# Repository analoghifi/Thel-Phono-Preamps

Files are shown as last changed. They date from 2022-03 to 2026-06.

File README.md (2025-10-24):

### "High-End":  
* predecessor models:
  * "VX-5021P" 1996 ➔ https://web.archive.org/web/20160323223326/http://thel-audioworld.de/test/test.htm#VX5021
  * "Phono-M" 2006 ➔ https://web.archive.org/web/20070626215210/http://www.thel-audioworld.de/module/phono/phono-M.htm
  * "Phono-HQ" 12/2017 ➔ https://web.archive.org/web/20180203013342/http://www.thel-audioworld.de/module/phono/phono-hq.htm
* <b>\"<a href="/hardware/beautiful%20noise">Beautiful-Noise</a>\" 09/2018</b>  
Stereo module / 2 channels galvanically isolated / single ended inputs, single ended outputs  
two-stage passive RIAA-filter  
adjustable gain (6-step) / input resistance changeable (by soldering) / input capacity changeable (by soldering)  
➔ https://web.archive.org/web/20190110103246/http://www.thel-audioworld.de/module/phono/Phonovorstufe-B.htm

### "Ultra-High-End":  
* predecessor models:
  * "Majestic" 1998 ➔ https://web.archive.org/web/20160323223326/http://thel-audioworld.de/test/test.htm#Majestic
  * "VP2000" 2002 ➔ https://web.archive.org/web/20020410123225/http://thel-audioworld.de/module/phono/phono.htm
  * "Phono-X" 2007-2017 ➔ https://web.archive.org/web/20070312044356/http://www.thel-audioworld.de/module/phono/phono.htm
  * "Phono HQX" 12/2017 ➔ https://web.archive.org/web/20180203012402/http://www.thel-audioworld.de/module/phono/phono-hqx.htm
* <b>\"<a href="/hardware/sound%20of%20silence">Sound of Silence</a>\" 09/2018</b>  
Mono module / true\* fully symmetrical / balanced input -> balanced filter stages -> balanced output  
\*(no ground reference at any point in the audio signal chain)  
two-stage passive balanced RIAA-filter  
adjustable input resistor (16-step) / adjustable input capacity (16-step) / adjustable gain (16-step)  
➔ https://web.archive.org/web/20190109011016/http://www.thel-audioworld.de/module/phono/Phonovorstufe-S.htm  

----  
calculation of the R C Values for the passive 2-step (inverse) RIAA filter:  
https://docs.google.com/spreadsheets/d/1qcIyMvDhxXAbTDFzf901tkU7BbxNvI2y0nLj_5HbEa4/edit?usp=sharing  

----  
#### "Beautiful-Noise":  
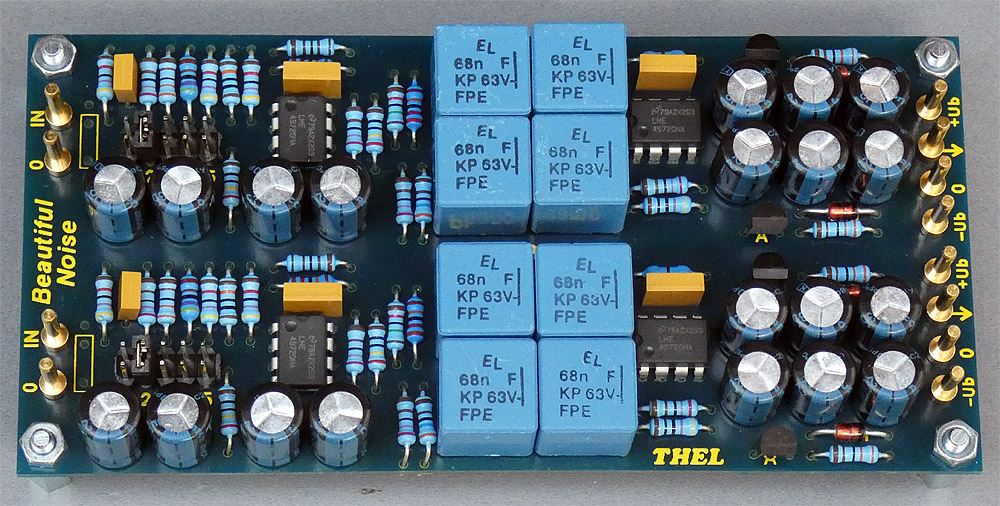
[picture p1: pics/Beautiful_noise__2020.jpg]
  
  
.  
  
#### "Sound of Silence":  
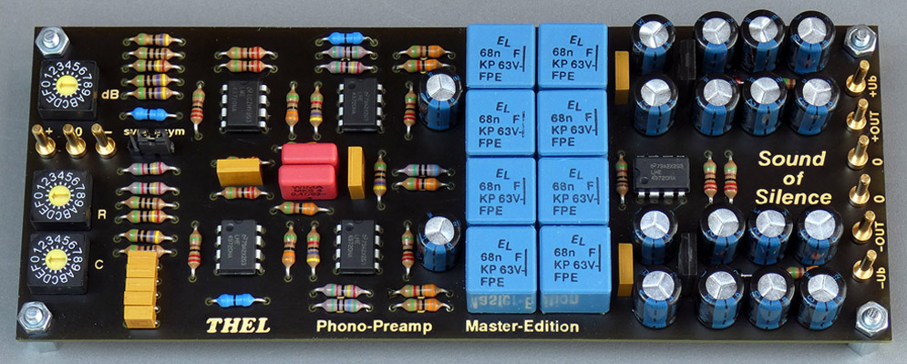
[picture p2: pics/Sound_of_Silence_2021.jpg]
  
  
----  
### Kicad projects in this repo:  
* ["Sound of Silence"](https://github.com/analoghifi/Thel-Phono-Preamps/tree/main/hardware/sound%20of%20silence/KiCad/original) | state: initial release v1.01 | like the original, 1-layer, THT
* ["Sound of Silence WIMA Edition"](https://github.com/analoghifi/Thel-Phono-Preamps/tree/main/hardware/sound%20of%20silence/KiCad/WIMA-Edition) | state: initial release v1.01 | all WIMA Caps | like the original, 1-layer, THT
* ["Beautiful Noise"](https://github.com/analoghifi/Thel-Phono-Preamps/tree/main/hardware/beautiful%20noise/KiCad/original) | state: coming soon... | like the original, 1-layer, THT

----

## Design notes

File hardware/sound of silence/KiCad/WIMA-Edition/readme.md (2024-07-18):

### This special edition exclusively uses the highly valued WIMA polypropylene capacitors throughout  
(FKP = highest quality film/foil types for the passive RIAA filter and the input (load-) Capacitors)  
* C101,C102,C201..C214 = WIMA FKP2 33nF 63V 1% (tanδ = 0.0005)  
* C3,C4,C6 = WIMA FKP2 100V 1% (tanδ = 0.0005)
* C5,C7 = WIMA FKP2 47pF 1000V 2.5% (tanδ = 0.0005)
* C8,C9,C12,C13,C14,C15 = WIMA MKP2 63V 5% (tanδ = 0.0005)  
  
see -> [List of used capacitors for the "WIMA-Edition"](https://github.com/analoghifi/Thel-Phono-Preamps/blob/main/hardware/sound%20of%20silence/KiCad/WIMA-Edition/Capacitor_BOM.md)  
  
#### this is not the original Thel PCB but it's very like\* the original with the following exceptions:  
* different board dimensions original: 155mm x 60mm -> this PCB: 155mm x 64mm  
* different mounting hole spacing original: 148mm x 53mm -> this PCB: 148mm x 57mm  
* "C2" is 462nF (paralleled 14x33nF Wima FKP2 1%) 
* "C1" is 66nF (paralleled 2x33nF Wima FKP2 1%)
* "C1" is in a different location on the board  
* using WIMA FKP2 (instead of ceramics) for the input (load-) Capacitors as well C3 ..C7  
* more massive ground and power supply PCB tracks  
* additional GND track unterneath U1 and U2 
  
\*(same schematic / same 1-layer\** layout THT / same THT components in the same places on the board)  
\**(strictly speaking, this KiCad PCB is a two-layer PCB with plated-through holes, but you can also (let) produce it as a classic 1-layer PCB with non-plated holes if you wish, since all the tracks are on the bottom side only)  

----  

### remarks:  
#### R6,R7:  
one can use 23,7kΩ or 24kΩ instead  
or use 2x47kΩ in parallel each  
when using MM-Systems (choosing R<sub>in</sub> = 47kΩ [SW2=0]):  
for lower noise one may use low-TCR-types (25ppm/°C or lower) if available  
e.g. Vishay "[CMF Industrial](https://www.mouser.com/c/passive-components/resistors/film-resistors/metal-film-resistors-through-hole/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)" series  
or Vishay [PTF series](https://www.mouser.de/c/passive-components/resistors/film-resistors/metal-film-resistors-through-hole/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) (even lower TCR)  
or Tyco (TE Connectivity) type "[YR1B23k7CC](https://www.mouser.com/ProductDetail/TE-Connectivity-Holsworthy/YR1B23K7CC?qs=n4i9pByFsMSkJXItUSDcPw%3D%3D)" (23.7kΩ / 0.1% / 15ppm/°C) [from the Tyco ["YR1-series" (R-series)](https://www.mouser.com/c/passive-components/resistors/film-resistors/metal-film-resistors-through-hole/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)]  
#### U1,U2,U3,U4,U5:  
instead of [LME49720](https://www2.mouser.com/ProductDetail/Texas-Instruments/LME49720NA-NOPB?qs=7lkVKPoqpbYtIqwyg5iDaA%3D%3D) you can use [LM4562](https://www2.mouser.com/ProductDetail/Texas-Instruments/LM4562NA-NOPB?qs=QbsRYf82W3Gc2w4DLq%252BZjw%3D%3D) (both Texas Instruments),  
these two are 100% identical (even regarding their inner guts).
  
----  
  
these are KiCad 6.x projects  
see how to get the proper 3D-Models from here: https://github.com/analoghifi/KiCad-3D-Models
  
----  
  
use kicanvas.org to view this KiCad project in your browser:  
https://kicanvas.org/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

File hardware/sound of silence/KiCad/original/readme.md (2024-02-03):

this is not the original Thel PCB but it's very like\* the original with the following exceptions:  
* different board dimensions original: 155mm x 60mm -> this PCB: 155mm x 69.65mm  
* different mounting hole spacing original: 148mm x 53mm -> this PCB: 148mm x 62mm  
* make use of my \"universal capacitor footprint\" for the filter caps (C1,C21,C22,C23,C24,C25,C26,C27) -> see here T.B.D.  
* C1 is in a different location on the board  
* using a combined 5.0mm/7.5mm pin spacing footprint for all other small (foil and ceramic) caps (C3,C4,C5,C6,C7,C8,C9,C10,C11,C14,C15)  
* more massive ground and power supply PCB tracks  
* additional GND track unterneath U1 and U2 
  
\*(same schematic / same 1-layer\** layout THT / same THT components in the same places on the board)  
\**(strictly speaking, this KiCad PCB is a two-layer PCB with plated-through holes, but you can also (let) produce it as a classic 1-layer PCB with non-plated holes if you wish, since all the tracks are on the bottom side only)  

----  

### remarks:  
#### C3,C4,C5,C6,C7:  
use ceramic C0G capacitors (tolerance: 1% to 2,5% / rated DC Voltage: 50V, 63V or 100V / pitch 5mm or 7,5mm)  
e.g. KEMET "[goldmax 300](https://github.com/analoghifi/capacitors/blob/main/audio%20and%20filter%20capacitors/docs/datasheets/C0G/KEMET_C1049_GOLDMAX_C0G_THT.pdf)" Series in THT version  
The dielectric material is important here: Do NOT use ceramic capacitors with a dielectric other than C0G (NP0) !  
or alternatively if you don't like ceramic capacitors:  
small polypropylene Film/Foil Capacitors (tolerance: 1% to 2,5% / rated DC Voltage: 63V or 100V / pitch 5mm or 7,5mm)  
e.g. KEMET [PFR-("Evox")](https://github.com/analoghifi/capacitors/blob/main/audio%20and%20filter%20capacitors/docs/datasheets/kp/KEMET_PFR_Serie_KP.pdf)-Series  
or WIMA [FKP2-Series](https://github.com/analoghifi/capacitors/blob/main/audio%20and%20filter%20capacitors/docs/datasheets/kp/WIMA_FKP_2__NEW_ROHS__EN.pdf) (not FKP**0**2)  
#### R6,R7:  
one can use 23,7kΩ or 24kΩ instead  
or use 2x47kΩ in parallel each  
when using MM-Systems (choosing R<sub>in</sub> = 47kΩ [SW2=0]):  
for lower noise one may use low-TCR-types (25ppm/°C or lower) if available  
e.g. Vishay "[CMF Industrial](https://www.mouser.com/c/passive-components/resistors/film-resistors/metal-film-resistors-through-hole/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)" series  
or Vishay [PTF series](https://www.mouser.de/c/passive-components/resistors/film-resistors/metal-film-resistors-through-hole/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) (even lower TCR)  
or Tyco (TE Connectivity) type "[YR1B23k7CC](https://www.mouser.com/ProductDetail/TE-Connectivity-Holsworthy/YR1B23K7CC?qs=n4i9pByFsMSkJXItUSDcPw%3D%3D)" (23.7kΩ / 0.1% / 15ppm/°C) [from the Tyco ["YR1-series" (R-series)](https://www.mouser.com/c/passive-components/resistors/film-resistors/metal-film-resistors-through-hole/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)]  
#### U1,U2,U3,U4,U5:  
instead of [LME49720](https://www2.mouser.com/ProductDetail/Texas-Instruments/LME49720NA-NOPB?qs=7lkVKPoqpbYtIqwyg5iDaA%3D%3D) you can use [LM4562](https://www2.mouser.com/ProductDetail/Texas-Instruments/LM4562NA-NOPB?qs=QbsRYf82W3Gc2w4DLq%252BZjw%3D%3D) (both Texas Instruments),  
these two are 100% identical (even regarding their inner guts).
  
----  
  
these are KiCad 6.x projects  
see how to get the proper 3D-Models from here: https://github.com/analoghifi/KiCad-3D-Models
  
----  
  
use kicanvas.org to view this KiCad project in your browser:  
https://kicanvas.org/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

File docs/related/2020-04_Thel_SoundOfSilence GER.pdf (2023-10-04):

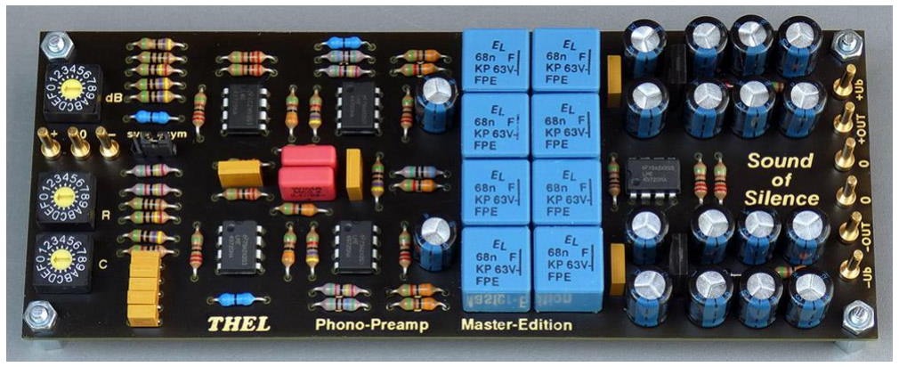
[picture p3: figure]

2020/05

# ERFAHRUNG/ HÖRERFAHRUNG THEL AUDIO „SOUND OF SILENCE “ PHONO PRE (ASYM)

M. Abraham

Einleitung

Bestellung

Aufbau

Erste Inbetriebnahme

Hör- Sessions

Resümee

## Einleitung

So, warum einen neuen Vor-Vorverstärker, um das mal Deutsch zu beschreiben.
1. Ich hatte Bock darauf
2. Ich habe z.Z. einen PhonoPre der am TA GraceF9 etwas zu leise ist
3. Lange gute Erfahrung mit Thel-Modulen und Herrn Hartwigs Versprechen >>
Zitat: „Wer dieses Schaltungs-Design einmal gehört hat, denkt hinterher anders übers Musikhören“

Vorweg, wer glaubt die eingebauten OP-Amp’s tauschen zu können, ... hm nicht ohne Weiteres, diese sind eingelötet. In unseren „Hifi-Teich“ ist ja unter anderen der OP-Amp-Tausch sehr beliebt, z.B. mit einer Australischen Marke.
Statement von Herrn Hartwig : „Da dieser OP in einer nicht nachvollziehbaren Preisklasse liegt, streift er nicht unser Interesse.“
Da hat er nicht ganz unrecht, es würden ca. 375€ dazu kommen. Will man das, bringt das was ? Muß jeder für sich entscheiden, ein Sockel für die OP-Amp’s hätte den Tausch leicht gemacht.

Testgeräte

Plattenspieler:
- Lenco L75/ MM - Grace F9, Soundsmith Nachbaunadel
- Elac 770H/ MM - D344, Jico HE796 Nadel
- Synq-1/ MM - ADC K8, K8E Nadel Tonacord

Vorhandener PhonoPre:
- Digna 1, Telefunken ECC8100
- Netzteil - Paul Hynes Design LTD, SR4S-19

Ca. Preise Stand 2020:

- Thel Phone Pre im Gehäuse (komplett) – 1000€
- Digna 1/ Telefunken – 650€
- Netzteil Paul Hynes – 400€

## Bestellung

Die Kosten eines Projektes sind immer ein Thema. Mein Motto ist, das was wichtig ist (die Aussage ist wohl relativ) wird gekauft, da entweder nicht vorhanden oder nicht gut genug.
Gehäuse – Ich hatte noch ein altes Blech/ Alugehäuse (als dem Schrott ausgesondert) aus medizintechnischer Fertigung . Die Qualität ist hervorragend und brachte z.B. die Kaltgerätebuchse mit Schalter mit. Der Deckel ist aus Alu, was aufgrund der Wärmeentwicklung sicher positiv sein wird. Unterhalb sind schon etliche Lüftungsschlitze, so daß ich guter Hoffnung war, die übermäßige Hitze der Class-A Netzteile „Herr“ zu werden.

Kabel – Für die Power Sektion hatte ich noch Kabel. Für den Phono-Part habe ich das Belden 8402 genutzt, welches sich als sehr gutes, erschwingliches Interconnect herausgestellt hat. Hier habe ich den Schirm mit Cinch-Masse verbunden.

Schrauben – nutze immer Edelstahlschrauben, ist evtl. ne Tick den ich aus der Medizintechnik habe und kostet immer etwas mehr.

Anschluß an die Phono-Module Thel- 2mm Stifte – da hatte ich bei dem Hoflieferanten Ama.. 2mm Buchse/ Steckerkombo geordert. Ich wollte ein Anlöten der Kabel auf den Platinen vermeiden, um evtl. später die Sym. Version des Thel-Pre’s zu realisieren.
Ich kann sagen das die Qualität des Zulieferer Ama... zu wünschen übrig läßt, so das ich die 2mm Buchsen von Thel empfehle, in der Hoffnung das diese von besserer Qualität sind.

Verbrauchsmaterialen – ja wie immer, Schrumpfschlauch in allen Kabelgrößen, Kabelbinder, usw.

Also was habe ich bei Thel bestellt (Stand: 2020-04):
Typ | Einz. EUR | Ges. EUR
2 x Sound of Silence | 215,00 | 430,00
2 x Netzteil Black-Pulsar 10 (http://www.thel-audioworld.de/module/Class-A%20Netzteil/Blackpulsar.htm) (ca. 2x 21V einstellen) | 118,00 | 236,00
4x CB-400G High-End Cinchbuchse | 4,90 | 18,60

## Aufbau

Es ist immer die Frage, welche Platinen, wo im Gehäuse zu plazieren, unter Berücksichtigung von z.B.
- Wärmeabfuhr
- Trafo zu einander/ zum Phonomodul (sollte möglichst größten Abstand haben)
- Genügend Platz für die Kabelverlegung
- Keine Behinderung mit hereinragenden Buchsen
- Aufgeräumte Kabelführung – kurze Wege, keine Kreuzungen
- Evtl. Upgrade mit sym. Buchsen oder Filter Modul
Denke Erfahrung hilft, wer schon einmal so etwas gemacht hat, hat den besseren Überblick. Wichtig ist, sich Zeit zu lassen bevor die Löcher der Stehbolzen gebohrt werden. Das ist meist schwierig, da die Finger „jucken“ und man sich der Fertigstellung entgegen sehnt. Rausgekommen ist – Abbildung 1

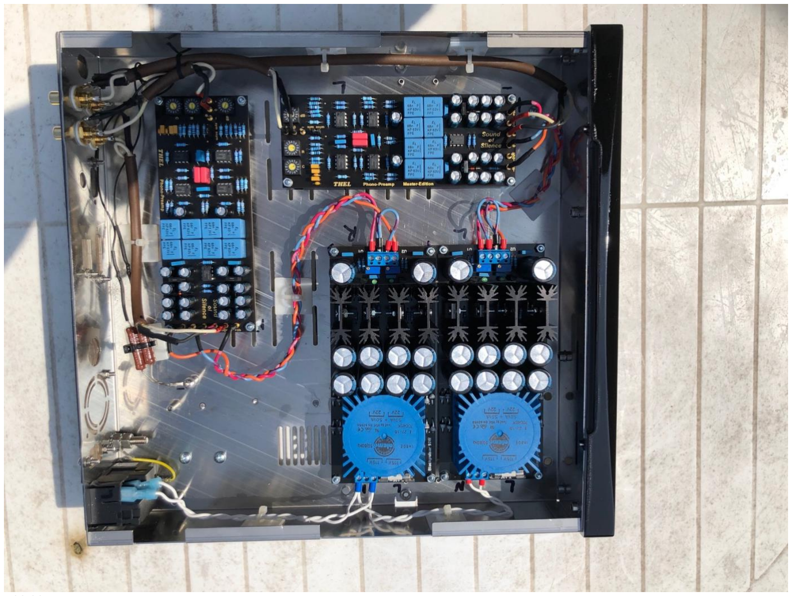
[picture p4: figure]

Abbildung 1

Noch was zum Kabelanschluß an die Power Module. Der Freiheitsgrad der Kabeldicke ist begrenzt aufgrund der Klemmengröße. Diese sind von hervorragender Qualität jedoch bei 1 Quadratmillimeter wird’s eng. Warum – es müssen teilweise zwei Kabel unter eine Klemme. Da ich sauber/ sicher arbeiten möchte, verwende ich Kabelendhülsen. Das war ein bißchen gefummel, letztendlich jedoch erfolgreich.

Der Anschluß an die 2mm Stifte der Phonoplatinen sollte sich mit meinen Hoflieferanten 2mm Buchse leicht gestalten. Aber wie immer es kommt immer was dazwischen. Es sind wohl einige Buchsen zu groß (Aufstecken fast ohne Widerstand) oder zu kein (läßt sich nur wenig bis gar nicht. aufstecken).

Beruhigungsmaßnahmen am Gehäuse – hier habe ich partiell „Alubutyl“ Dämmmatte selbstklebend unterhalb des Gehäuses installiert ohne die Lüftungsschlitze zu blockieren.

Cinch-Buchsen – gute Qualität und lassen sich mühelos installieren.

Rückwand Gehäuse/ Anschlussfeld – ich sprach ja von einem gebrauchten Gehäuse und damit waren Ausbohrungen vorhanden die ich teilweise nutzen konnte, aber teilweise nicht. Letztendlich habe ich den vorhandenen alten Lüftereinlass offen gelassen und ansonsten mit einer passenden Vinylfliese den Rest verschlossen.

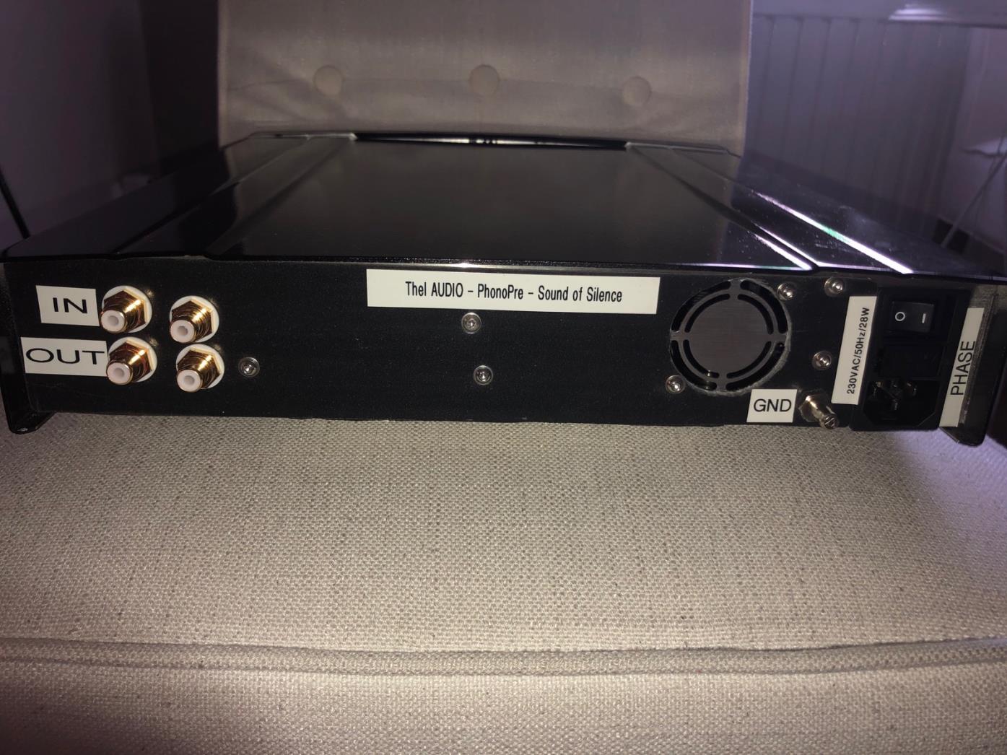
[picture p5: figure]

Abbildung 2

## Erste Inbetriebnahme

Zuerst alles ohne Deckel, da das Ausmaß der Hitzeentwicklung noch unklar war bzw. Verbesserungen evtl. nötig sind. Auch ein Herausfinden der Einstellungen der DIL-Switches (Kapazität, Verstärkung) war noch nicht 100% klar.
Ich war froh, nichts ist abgeraucht nach dem ersten Einschalten, man weiß ja nie, obwohl ich mehrmals alle Anschlüsse kontrolliert habe – so weit so gut.
Bekannte Scheibe abends um 23:00 Uhr aufgelegt und beim Bierchen den ersten Takten gelauscht. Spontane Gedanken kamen auf wie – voluminöser, mehr Stimmen, mehr Raum, ruhiger und man hatte den Drang die Plattenspielerdrehzahl zu kontrollieren, da der Eindruck aufkam, dieser dreht zu langsam.
Zu diesen Zeitpunkt hatte ich die empfohlene Masseverbindung noch nicht realisiert, was mit meinen Drehern auch funktioniert.

Im nächsten Schritt wollte ich die Temperatur bei geschlossenem Gehäuse messen. Der wärmste Punkt auf den Kühlkörpern der Netzteile stellte sich bei 62°C ein. Die extrem nahe verbauten Elkos sind mit dieser Hitze konfrontiert und erfahrungsgemäß nicht optimal. Nach studieren der Specs war klar, das Herr Hartwig das berücksichtig hatte und Elkos mit max. Temp. von 105°C verbaut wurden. Ich zitiere mal aus seinem Prospekt „Info zur Elko Temperatur: Die Elkos sind ausgesuchte LOW-ESR 105° Typen. Bei ca. 85° Grad Kühlertemperatur pendelt sich die Elko Temperatur bei ca. 50° Grad ein.“

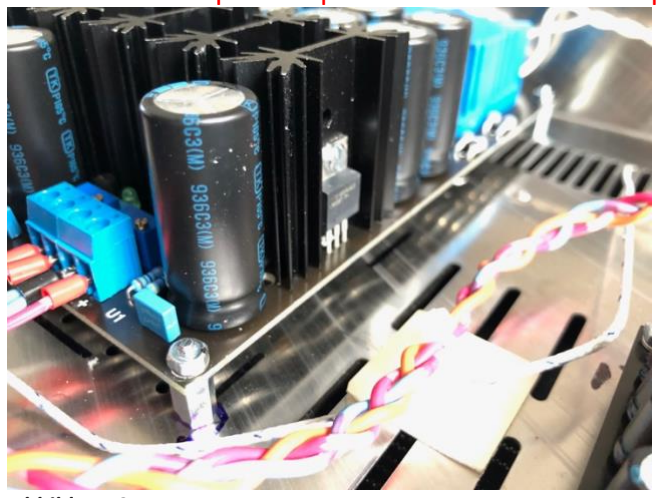
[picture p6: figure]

Abbildung 3

Eine Messung zwischen den Elkos ergab ca. 56 °C. Ich stellte mir die Frage was ich evtl. daran verbessern könnte. Definitiv wollte ich an der Rückwand die Lüfterschlitze wieder freilegen.
Danach war die Fragen, ob zwei Maßnahmen die Temperaturbedingungen evtl. verbessern.
1. 6cm, 24VDC Lüfter einbauen
2. Abstand der Power Module zu einander vergrößern.

Punkt 1. Realisierte ich, jedoch wurde klar das bei 24VDC zwar die Lüftungsperformance gut ist, jedoch ich eine Turbine beim Platten hören höre. 9VDC Lüfterbetriebsspg. sind zu schwach und 12VDC erschienen ein guter Kompromiß. Die Temp. stellte sich niedriger ein, jedoch über alles immer noch zu laut – also habe ich die Idee verworfen.

Punkt 2. Habe ich noch nicht realisiert und wird sicher etwas nützen, ändert aber nix an der Temp. zwischen den Elkos. Diese Maßnahme würde unteranderen auch den Abstand zu den Phono Platinen verringern, was ich eigentlich nicht vorhatte.

Einspielen – jetzt werden einige sicher aufhorchen und sagen das ist alles Mumpitz, .... hmm, ich kann nur sagen das sowas nach meiner persönlichen Erfahrung schon Effekte hat. Wie auch immer, ich kann berichten, das nach 3x Nächten, gefüttert mit einem mobilen Player auf kleinster Lautstärkestufe, das Klangbild erheblich „Erwachsener“ geworden ist.

## Hör – Sessions

So nun kommt der schwierigste Teil und alles subjektiv. Ach bevor ich es vergesse, Hörsessions erfolgten nur mit MM Systemen. Beide Phono-Pre können MM und MC mit toller flexibler, praxisgerechter Anpassungsmöglichkeit.

In meinen Kopf stellt sich die Frage, wo die Sound of Silence liegt, im Vergleich zum Digna Phono Pre, der definitiv ein wunderbarer Pre-Amp ist. By the way, Made in Germany toller Support von Jürgen Grau.

Hörsession 1: Gemeint ist nicht die erste Hörsession, sondern die erste Stufe.
Ich höre erstmal alles durch und nutze nur den Thel-Pre und beschreibe meine Eindrücke.

Hörsession 2: Weiß jetzt wie der Thel-Pre klingt (hat jetzt mehr Betriebstd. drauf) und fange an, den A - B Vergleich dar zu stellen.

Hörsession 1:
Wie gesagt, hat der Thel-Pre jetzt einige Std. schon drauf. Ich muß feststellen das sonst leichte Phono-Pre Brummen (hat mich nie gestört) gar nicht oder reduzierter vorhanden ist. Verstärkung ist auf 44,2dB, C=367µF und 47K für MM Systeme.
Stimmen „spucken“ mich an, die Bühne ist größer. Details sind durchweg hörbar, spez. die kleinen die in vielen Stücken mit vermindertem Pegel im Hintergrund laufen. Und das Klangbild ist ruhig. Manchmal scheint die Frage auf zu kommen, ist das weniger Attacke, langweiliger oder einfach nur richtiger. Mein Musikbuddy (Röhrenfan schlecht hin) kam mit der Aussage, klingt technischer, weniger analog. Hallo.... das ist eine Analogketten mein Freund. Ich weiß was er meinte und im A-B Vergleich später checken wir das nochmal und dann hat der Thel-Pre auch ein paar mehr Std. drauf.

Hörsession 2:

So, auf zum Duell mit dem Digna. Was soll ich sagen, der Digna ist nicht schlecht, der Thel sticht aber positiv(er) heraus. Z.B. bei Georg Michael, Album Faith, Song „Hand to Mouth“ , die Bühne ist größer, der Punch und diese Platte hat davon ne ganze Menge, geht noch mehr in die Magengrube. Es geschieht musikalisch einfach mehr, es ist mehr los auf der Bühne. Stimmen gefallen mir schmelziger, intensiver. Über alles scheint der Digna in dieser Konfiguration der kleinere Bruder zu sein. Die Hörsession 1 Aussage, weniger Attacke kann getrost zu den Akten gelegt werden, eine gewisse Einspielzeit wird immer wieder bestätigt, wie auch hier.

## Resümee

Wir sind uns alle einig, mein Vergleich ist eine subjektive „Aufnahme“. Ich war mit dem Digna zufrieden, aber es geht halt noch besser. Es sei hier fährerweise gesagt, das der Digna mit einen sehr guten DC Netzteil angetrieben wurde. Auch der Thel wird sich wohl auf dem Klangniveau bewegen auf dem er ist, aufgrund seiner guten Netzteile, denn wie wir wissen, was vorne schon nicht richtig gemacht wird, kann hinten nicht besser werden.
Mir ist wichtig gewesen, ein Bericht zu erstellen der zum Selbstbau motiviert und so was wie etwas Sicherheit gibt, wo man mit dem Thel Gerät steht. Leider hat der Selbstbau, zwecks grober Kaufentscheidung, wenig Lobby oder Führsprecher a la Magazine. Ich hoffen ich konnte hier aushelfen.

Viel Spaß beim Musik hören.

Mit besten Grüßen
Abi

Tips:
- Kontakte immer fettfrei halten, Isoprophylalkohol sollte mit sauberen Baumwolllappen immer griffbereit stehen. Lange leben die alten Unterhosen .
- Bohrungen für Platinen sehr präzise bohren, heißt M3 Befestigungsschrauben müssen absolut genau „fluchten“, ansonsten riskiert man „Verspannungen“ der Platinen. Daran denken, es ist warm im Gehäuse und Material „arbeitet“ immer.
- Internes Powerkabel/litzen immer verdrillen. Bringt saubere Kabelführung und elektrotechn. Besserung.
- Gehäuse nicht zu klein wählen, guten Kompromiß zwischen Wärmeabfuhr, Abstand und saubere Kabelverlegung finden.
- Gute Wärmeabfuhr bewerkstelligen. Je weniger Streß auf den Materialien desto besser.

Links:

Digna Homepage: http://www.nixiekits.eu/index.php Paul Hynes Design: https://www.paulhynesdesign.com/

Thel Homepage: http://www.thel-audioworld.de/

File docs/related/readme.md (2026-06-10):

source of the document: 2020-04_Thel_SoundOfSilence GER.pdf:  
https://www.diy-hifi-forum.eu/forum/showthread.php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  
(german internet forum)  

source of the document: 2020-04_Thel_SoundOfSilence EN.pdf:  
same document/source as above but automatically translated with deepl.com  

source of the document: The capacitance multiplier revisited.pdf:  
https://electrical.codidact.com/posts/279580

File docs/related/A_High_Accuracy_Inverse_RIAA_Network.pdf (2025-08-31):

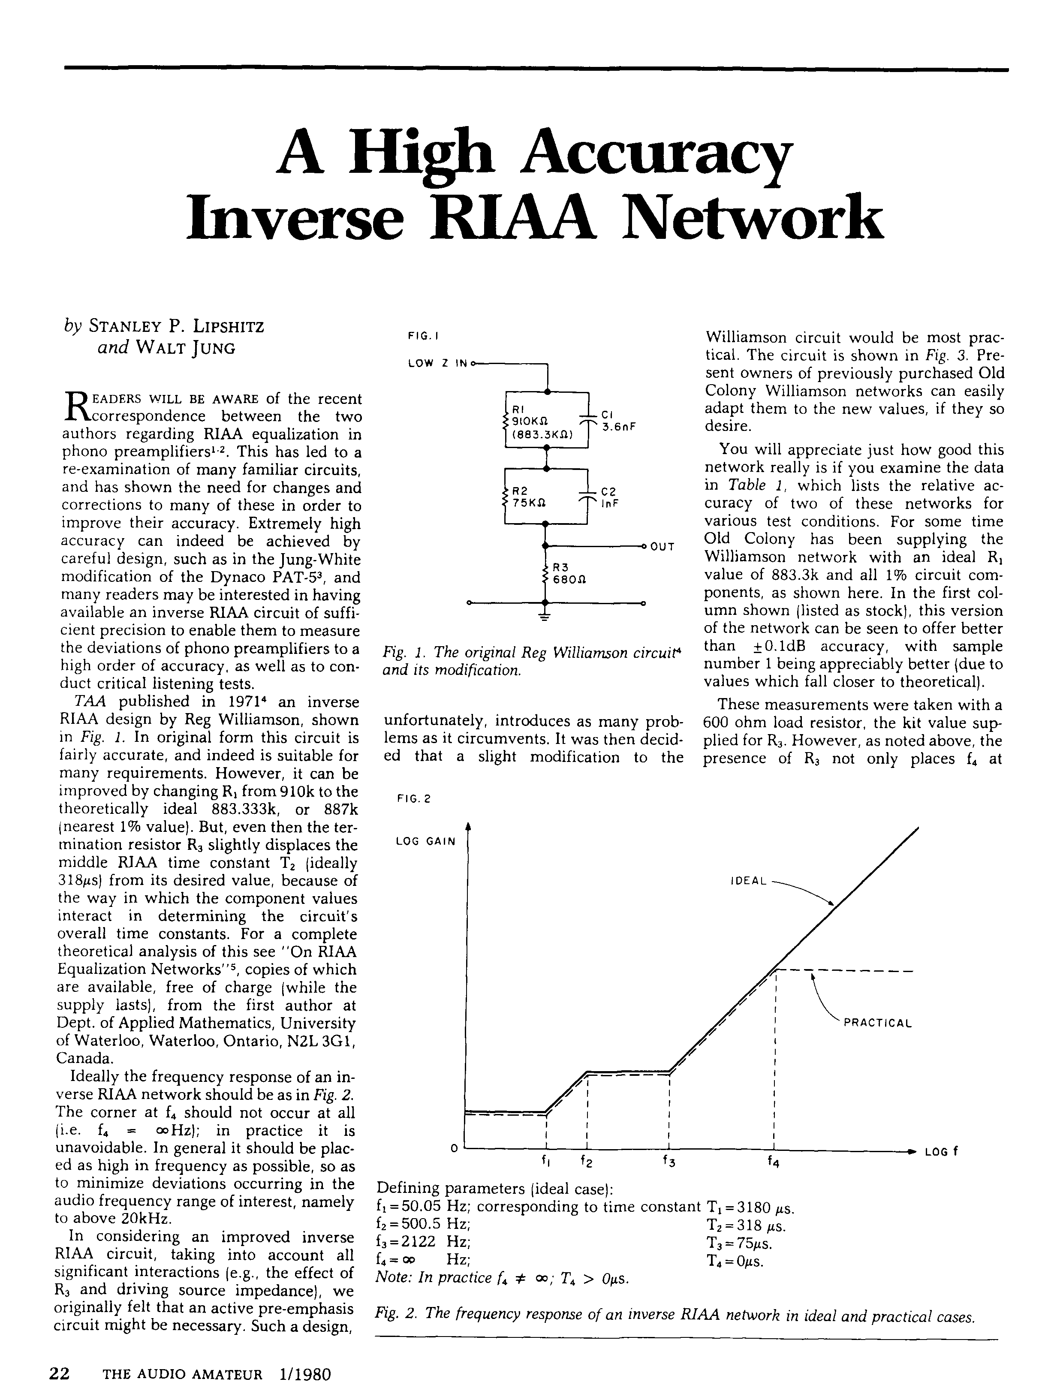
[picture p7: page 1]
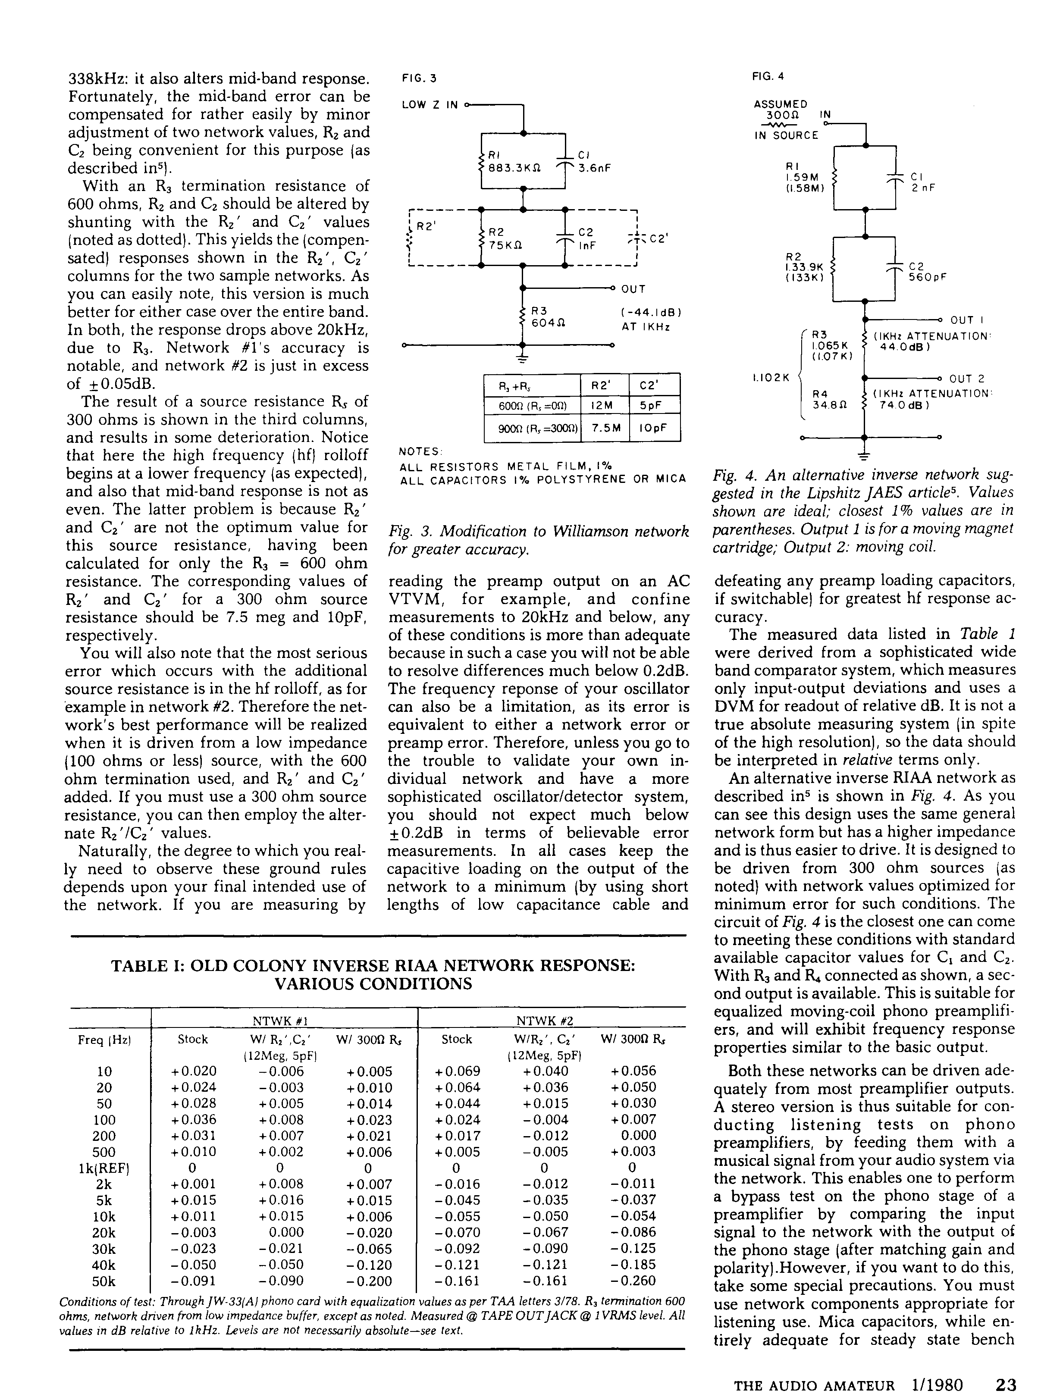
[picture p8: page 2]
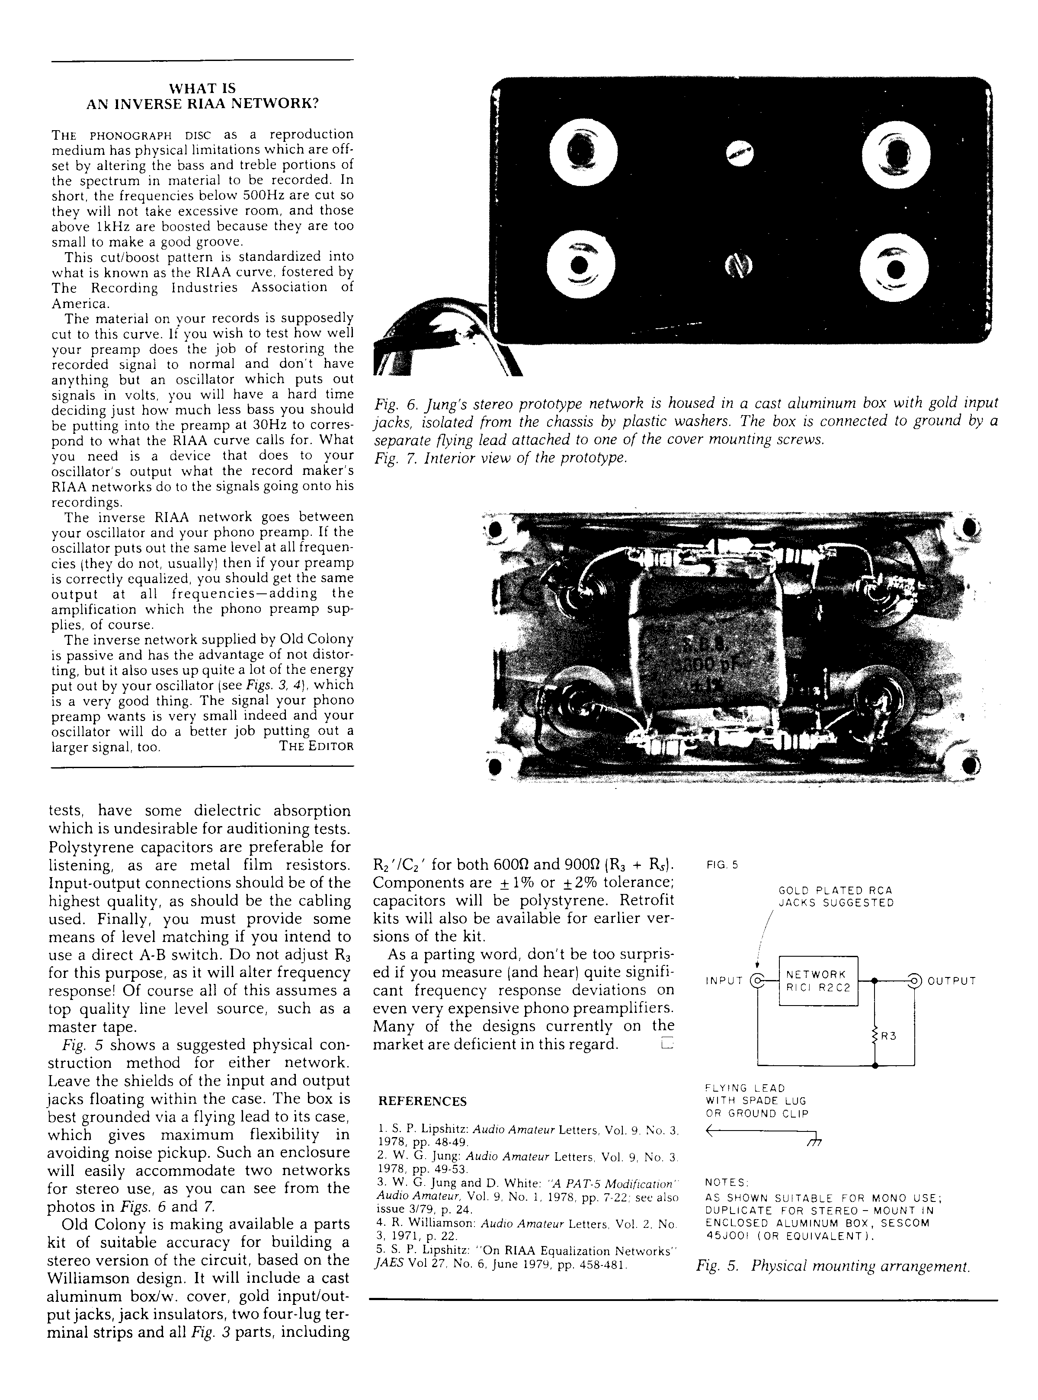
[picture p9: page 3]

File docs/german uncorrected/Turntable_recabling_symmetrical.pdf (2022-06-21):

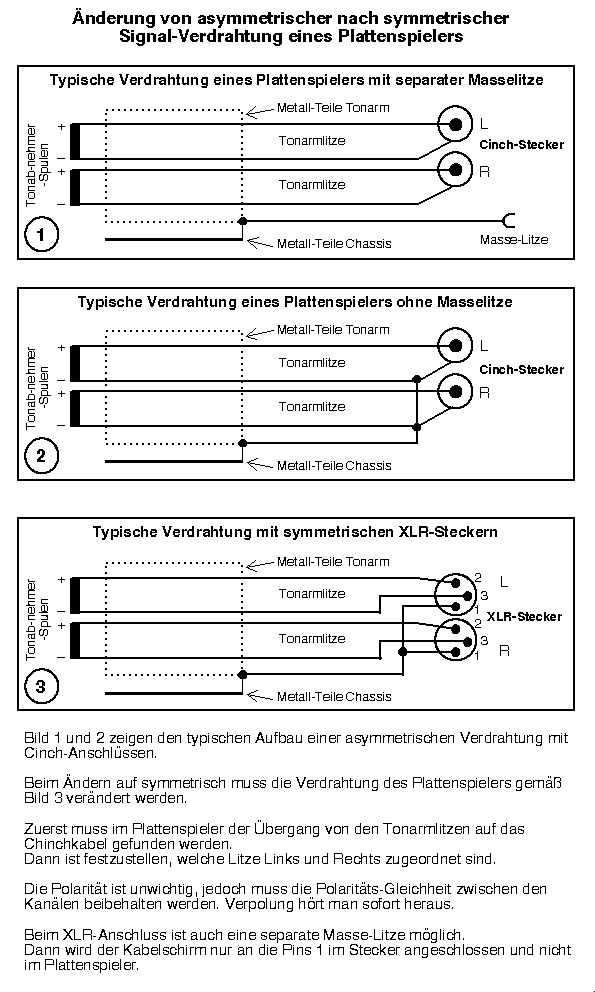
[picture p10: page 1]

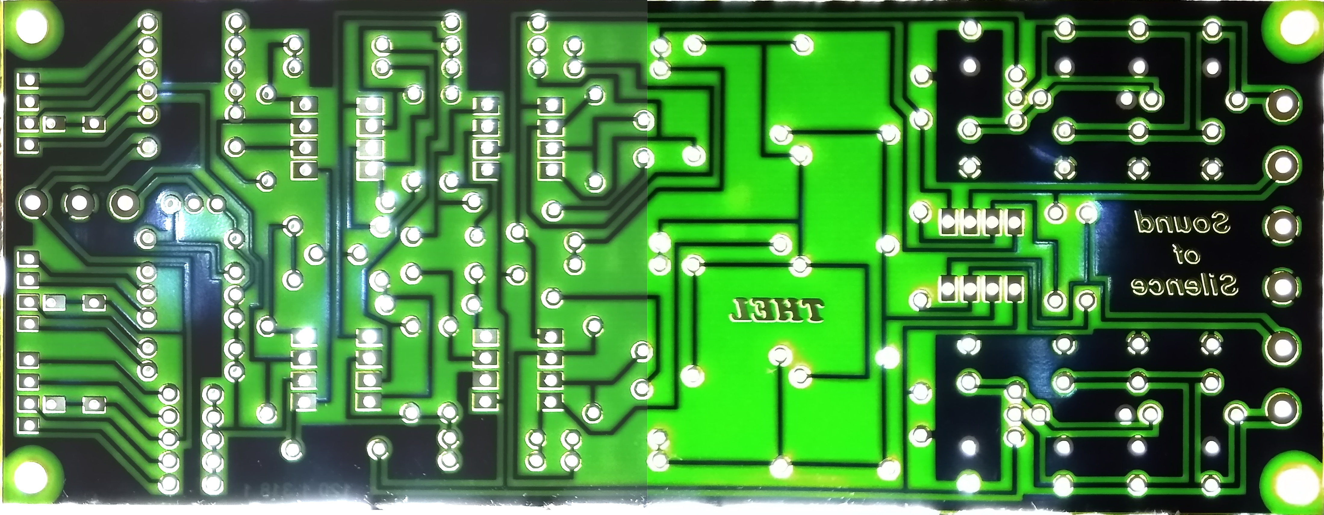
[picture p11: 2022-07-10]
hardware/sound of silence/PCB_SoS_Bottom_shine_through_mirror.jpg

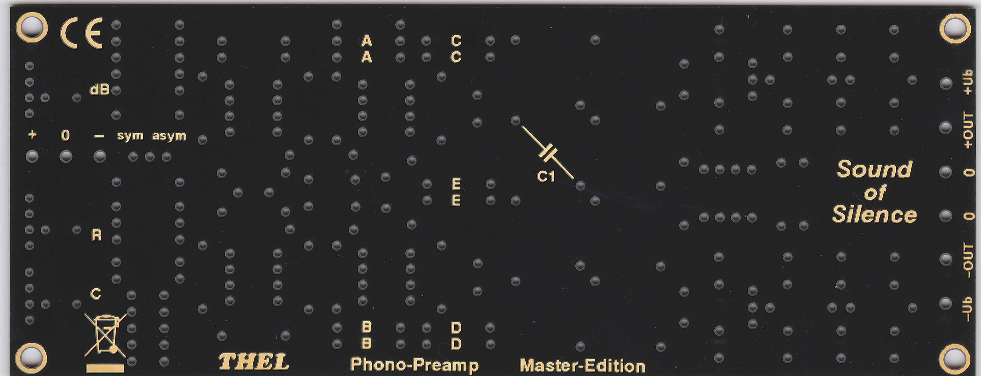
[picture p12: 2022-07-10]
hardware/sound of silence/PCB_SoS_Top.jpg

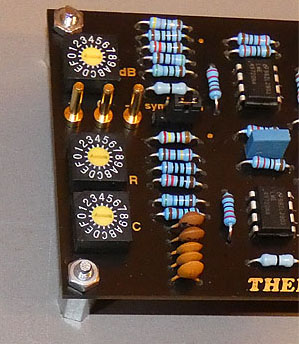
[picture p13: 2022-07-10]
hardware/sound of silence/SoS-3.jpg

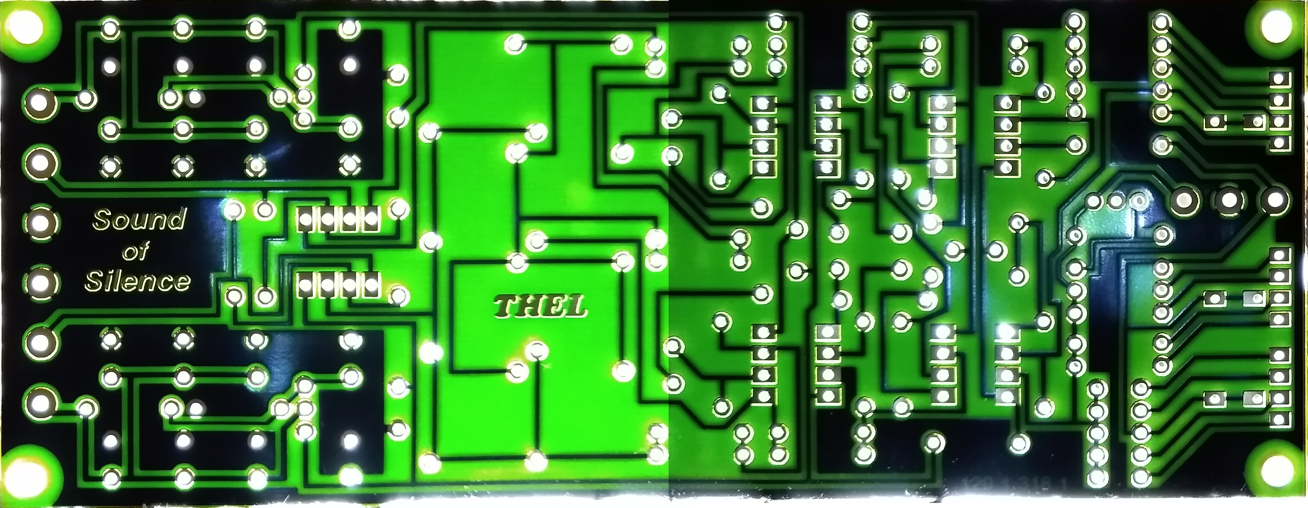
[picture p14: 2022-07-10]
hardware/sound of silence/PCB_SoS_Bottom_shine_through.jpg

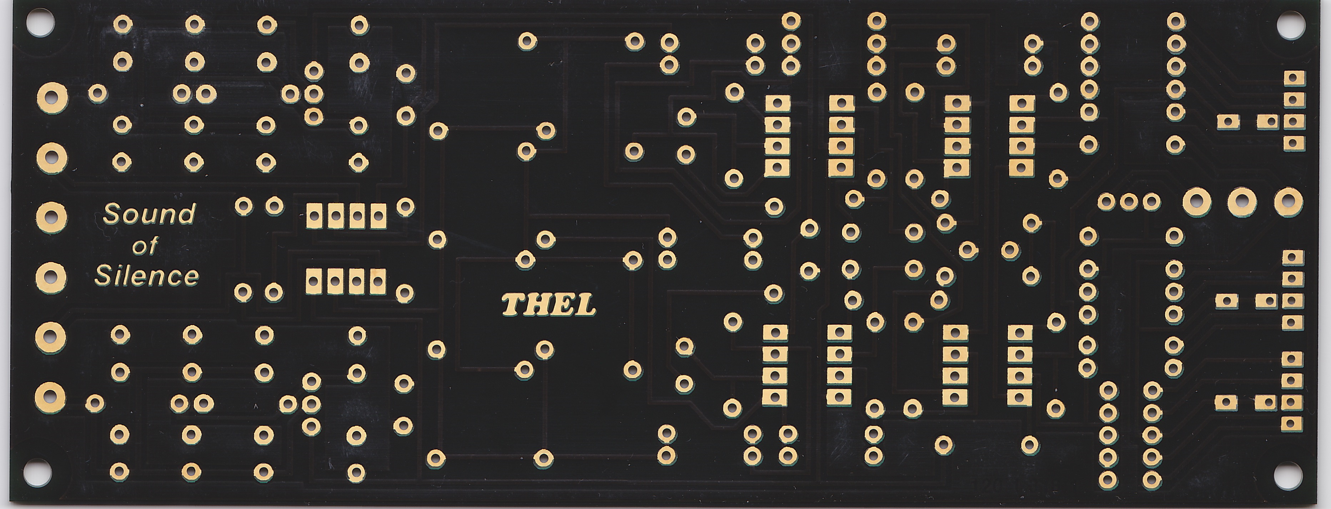
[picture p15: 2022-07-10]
hardware/sound of silence/PCB_SoS_Bottom.jpg

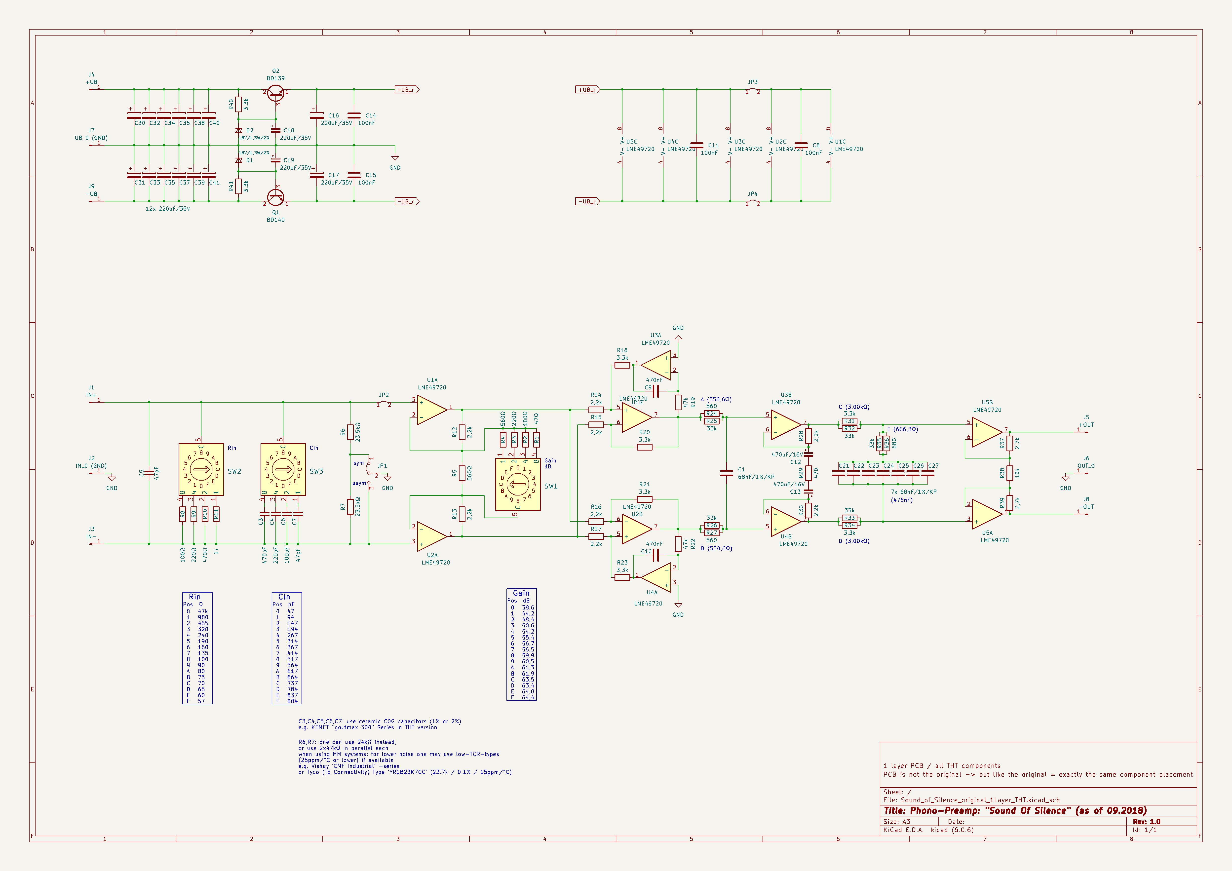
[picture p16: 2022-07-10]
hardware/sound of silence/KiCad/original/Sound_of_Silence_original_1Layer_THT.sch.png

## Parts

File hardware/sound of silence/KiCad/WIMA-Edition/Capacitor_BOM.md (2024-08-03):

### List of used Capacitors for the "WIMA-Edition"  

Quantity | Component | Value | Manufacturer/Series | Manuf.-Type | Vendor | Vendor-Art.-No
-------- | -------- | -------- | -------- | -------- | -------- | --------
2 | C8, C9 | 470nF 63V 5%  | WIMA / MKP2 | [MKP2C034701M00J](https://octopart.com/search?q=MKP2C034701M00J)   | ? | ?  
-> | alternative C8, C9 | 470nF 100V 5%  | WIMA / MKP2 | [MKP2D034701M00J](https://octopart.com/search?q=MKP2D034701M00J) | Mouser | [505-MKP2D034701MJSSD](https://eu.mouser.com/ProductDetail/WIMA/MKP2D034701M00JSSD?qs=RB4whv9F6rz11gXdVVfF6w%3D%3D)
4 | C12 .. C15 | 100nF 63V 5%  | WIMA / MKP2 | [MKP2C031001F00J](https://octopart.com/search?q=MKP2C031001F00J) | Mouser | [505-MKP2C031001F00JS](https://eu.mouser.com/ProductDetail/WIMA/MKP2C031001F00JSSD?qs=iPPgFPFs9PMcd%252BYU%252BMRHkw%3D%3D)
-> | alternative C12 .. C15 | 100nF 100V 5%  | WIMA / MKP2 | [MKP2D031001F00J](https://octopart.com/search?q=MKP2D031001F00J) | Mouser | [505-MKP2D031001FJI00](https://eu.mouser.com/ProductDetail/WIMA/MKP2D031001F00JI00?qs=sJjjjplDs9u1SRmPcC2duw%3D%3D)
16 | C101, C102, C201 .. 214 | 33nF 63V 1% | WIMA / FKP2 | [FKP2C023301L00E](https://octopart.com/search?q=FKP2C023301L00E) | buerklin.com | [42D8428](https://www.buerklin.com/en/p/wima/film-capacitors/fkp2c023301l00essd/42D8428/)
1 | C3 | 470pF 100V 1% | WIMA / FKP2 | [FKP2D004701D00E](https://octopart.com/search?q=FKP2D004701D00E) | buerklin.com | [42D8438](https://www.buerklin.com/en/p/wima/film-capacitors/fkp2d004701d00essd/42D8438/)
1 | C4 | 220pF 100V 1% | WIMA / FKP2 | [FKP2D002201D00E](https://octopart.com/search?q=FKP2D002201D00E) | buerklin.com | [42D8434](https://www.buerklin.com/en/p/wima/film-capacitors/fkp2d002201d00essd/42D8434/)
1 | C6 | 100pF 100V 1% | WIMA / FKP2 | [FKP2D001001D00E](https://octopart.com/search?q=FKP2D001001D00E) | buerklin.com | [42D8430](https://www.buerklin.com/en/p/wima/film-capacitors/fkp2d001001d00essd/42D8430/)
2 | C5, C7 | 47pF 1000V 1% | WIMA / FKP2 | [FKP2O100471D00E](https://octopart.com/search?q=FKP2O100471D00E) | ? | ?
-> | alternative C5, C7 | 47pF 1000V 1.5% | WIMA / FKP2 | [FKP2O100471D00F](https://octopart.com/search?q=FKP2O100471D00F) | ? | ? 
-> | alternative C5, C7 | 47pF 1000V 2% | WIMA / FKP2 | [FKP2O100471D00G](https://octopart.com/search?q=FKP2O100471D00G) | ? | ?
-> | alternative C5, C7 | 47pF 1000V 2.5% | WIMA / FKP2 | [FKP2O100471D00H](https://octopart.com/search?q=FKP2O100471D00H) | Mouser | [505-FKP2O10471D0HO0](https://eu.mouser.com/ProductDetail/WIMA/FKP2O100471D00HO00?qs=WI052HLiD5gTYAbXe%2FIo1g%3D%3D)
-> | alternative C5, C7 | 47pF 500V 1% silver mica | Cornell Dubilier (CDE) - Knowles / CD15 Series | [CD15ED470DO3F](https://octopart.com/search?q=CD15ED470DO3F)<br>[CD15ED470FO3](https://octopart.com/search?q=CD15ED470FO3) | Farnell<br>Mouser| [1264876](https://de.farnell.com/en-DE/cornell-dubilier/cd15ed470do3f/cap-47pf-500v-1-through-hole/dp/1264876)<br>[5982-15F-500V47](https://eu.mouser.com/ProductDetail/Cornell-Dubilier-CDE/CD15ED470FO3?qs=9iVfQKk8ifFmXLRqX5bCNQ%3D%3D)
-> | alternative C5, C7 | 47pF 250V 1% C0G ceramic | KEMET / Goldmax 300 | [C327C470FAG5TA](https://octopart.com/search?q=C327C470FAG5TA)**\*** | Mouser | [80-C327C470FAG5TA](https://eu.mouser.com/ProductDetail/KEMET/C327C470FAG5TA?qs=h3%2Fj8evtlm1OqcZUJ%2F%2FGqA%3D%3D)
-> | alternative C5, C7 | 47pF 100V 1% C0G ceramic| KYOCERA / AVX | [SR211A470FAA](https://octopart.com/search?q=SR211A470FAA) | Mouser | [581-SR211A470FAA](https://https://eu.mouser.com/ProductDetail/KYOCERA-AVX/SR211A470FAA?qs=k4kUdCzLgS5qmJCMYEwoiw%3D%3D)

WIMA [FKP2-Series Datasheet](https://github.com/analoghifi/capacitors/blob/main/audio%20and%20filter%20capacitors/docs/datasheets/kp/WIMA_FKP_2__NEW_ROHS__EN.pdf) (Polypropylene (PP) Film/Foil Capacitors)  

WIMA [MKP2-Series Datasheet](https://github.com/analoghifi/capacitors/blob/main/audio%20and%20filter%20capacitors/docs/datasheets/mkp/e_WIMA_MKP_2.pdf) (Metallized Polypropylene (PP) Film Capacitors)  
  
.  
  
**\***(you can use the following KEMET Goldmax 300 Types (47pF 250V 1% C0G ceramic) as well:
[C317C470FAG5TA](https://octopart.com/search?q=C317C470FAG5TA)  
[C318C470FAG5TA](https://octopart.com/search?q=C318C470FAG5TA)  
[C322C470FAG5TA](https://octopart.com/search?q=C322C470FAG5TA)  
[C323C470FAG5TA](https://octopart.com/search?q=C323C470FAG5TA)  
[C325C470FAG5TA](https://octopart.com/search?q=C325C470FAG5TA)  
[C327C470FAG5TA](https://octopart.com/search?q=C327C470FAG5TA)  
[C328C470FAG5TA](https://octopart.com/search?q=C328C470FAG5TA)  )

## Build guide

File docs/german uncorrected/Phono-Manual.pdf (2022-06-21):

# Sound of Silence

Für sym oder asym Eingang muss der Jumper richtig gesteckt sein.

# sym asym I!.lftgllg, lr I

(symmetnsch)

Es muss eine.symmetrische (t) Betriebsspannung angelegt werden. Das obere Beispielzeigt, wie diese aus zwei Einzelspännungen gewonnen werden karyr. Die optimale Höhe der Betriebsspann-ung siehe unten. Eine höhere Sp.annung als *optimal" bewirkt kein'e Klangf ververbessglun"g. Wird der symmetrische Ausgang unsymmetrlsch betrieben (Cinch), wird nur '+OUT' verwendetl'-öUT'-bleibt dann unbelegt. Die Module sollten unbedingt in ein metallisches Gehäuse eingebäut werden. Das Gehäuse mu§s mit dem GND-Ansctrluss (Öi verbunden werden. Wird ein nicht leitendes Gehäuse bevorzugt (2.8. Holz), muss zumindest unter der Leiterplatte ein leitendes Bbdn ' montiert werden, dass mit GND verbunden wird.

Ausgang
Cinchbuchse

EI,'

Pos dB

# 0 39,6 1 M,2 2 49,4 3 50,6 4 54,2 5 55,4 6 56,7 7 56,5 I 5g,g I 60,5 A 61,3 B 61,9

c 63,5 D 63,4 E 64,0 F 64,4

E-

Pos O

# 0 47k 1 980 2 465 3 320 4 24A 5 190 6 160 7 135 I 100 990 480 875 c70 D65 E60 F57

weitere
hinzugerechnet

o"l

I

Pos oF

I

0 47 I
1 e4 I
2 1471 3 1s4l 4 2671 5 3141 6 3671 7 4141 8 5171

e 5641 A 6171 B 6641 c 7s7l D 7ul E ffi71 F 8841

Stufenschalter für die Eingangsparameter
dB = Verstärkung bei l kHz ff,.| ._ | Phonovorstufe am
l(J;ou Lausprecher in etwa den gleichen Pegel aufweist, wie

die anderen an die Anlage angeschlossenen Geräte.

des Herstellers

werden müssen. Daher ist die tatsächliche tapaTitve Last nicht genau zu_ermitteln und muss ggf nach Gehör-eingestellt werden. C hat auf nierohmige MC-Systeme keinen Einfluss.

eingestellt. Dabei gilt zu berü
Kapazitäten, wie z.B. das Anr

Technische Daten

Betriebsspg (Ub)
optimal
Eigen-Stromaufn.
max. Ausg.spg.
max Ausgangsstrom
BIAA Genauigkeit typ
Subsonic

* 5V bis r25V max
*18V bis r21V
*60mA
2V unter Ub; max t16V
25mN32OQ
<0,02d8 (40H2-20kHz)
20Hz -0,6dB
1OHz -3dB

+

0

+ub

### ouT +0

o | -ub

# Beautiful-Noise

Cinchbuchsen
Eingang
(asymmetrisch)

Es muss eine symmetrische (t) Betriebsspannung angelegt werden.
Das obere Beisiliel zeigt, wie diese aus zwei EinzelspannlJngen gewonnen werden kann. Die optimale Höhe äer Betiiebsspannung siehe unten. Eine höhere Spannung_alq ]optinnal'bewirkt keine Kiangververbesserung. Die Module §ollten unbedingt in ein metallisches Gehäuse eingebaut werd-en. Das Gehäuse muss mit dem GND-Anschluss (0) verbunden werden. Wird ein nicht leitendes Gehäuse bevorzugt (2.8. Holz), muss zumindest unter der Leiterplatte ein leitendes Blech montiert werden, dass mit GND verbunden wird.

1= 39,6 dB
2= 41,1 dB
3= 43,7 dB

58,1 dB
60,8 dB
64,1 dB

4=
5=
6=

Verstärkungstaktor
Mit der S-poligen Stittleiste wird der Verstärkungsfaktor eingestellt
Die sechste Stufe wird eingestellt, indem keine Steckbrücke verwendet wird. Er kann zur Aufbewahrung auf die gestrichelte Markierung gesteckt werden. Werden mehrere Brücken gleichzeitig gesteckt, so kann die Verstärkung um Zwischenwerte experimentell verringert werden.

Eingangsparameter
Fest eingebaut sind 47 kA und 47pF
Neben den beiden Eingangspins sind Bohrungen vorgesehen, um diese Werte durch einlöten eines anderen Widerstands- oder Kondensatoruvert zu verändern, Für MM-Systeme ist der eingebaute 47 kA vorgesehen. Für MC-Systeme wird gemäß den Hersteller-Empfehlungen ein geringerer Widerstandswert eingelötet.
Für MM-Systeme wird gernäß den Hersteller-Empfehlungen ein größerer Kondensatorwert eingelötet.

Technische Daten

Betriebsspg (Ub)
optimal
Eigen-Stromaufn.
max. Ausg.spg.
max Ausgangsstrom
RIAA Genauigkeit typ
Subsonic

t 5V bis t25V max
t18V bis *21V
t60mA
2V unter Ub; max *16V
25mAl320A
<0,02d8 (40H2-20kHz)
20Hz -0,6d8
1OHz -3dB

## o lol o . o

## 11r | : .lll o:l ?:

12 3 4 5

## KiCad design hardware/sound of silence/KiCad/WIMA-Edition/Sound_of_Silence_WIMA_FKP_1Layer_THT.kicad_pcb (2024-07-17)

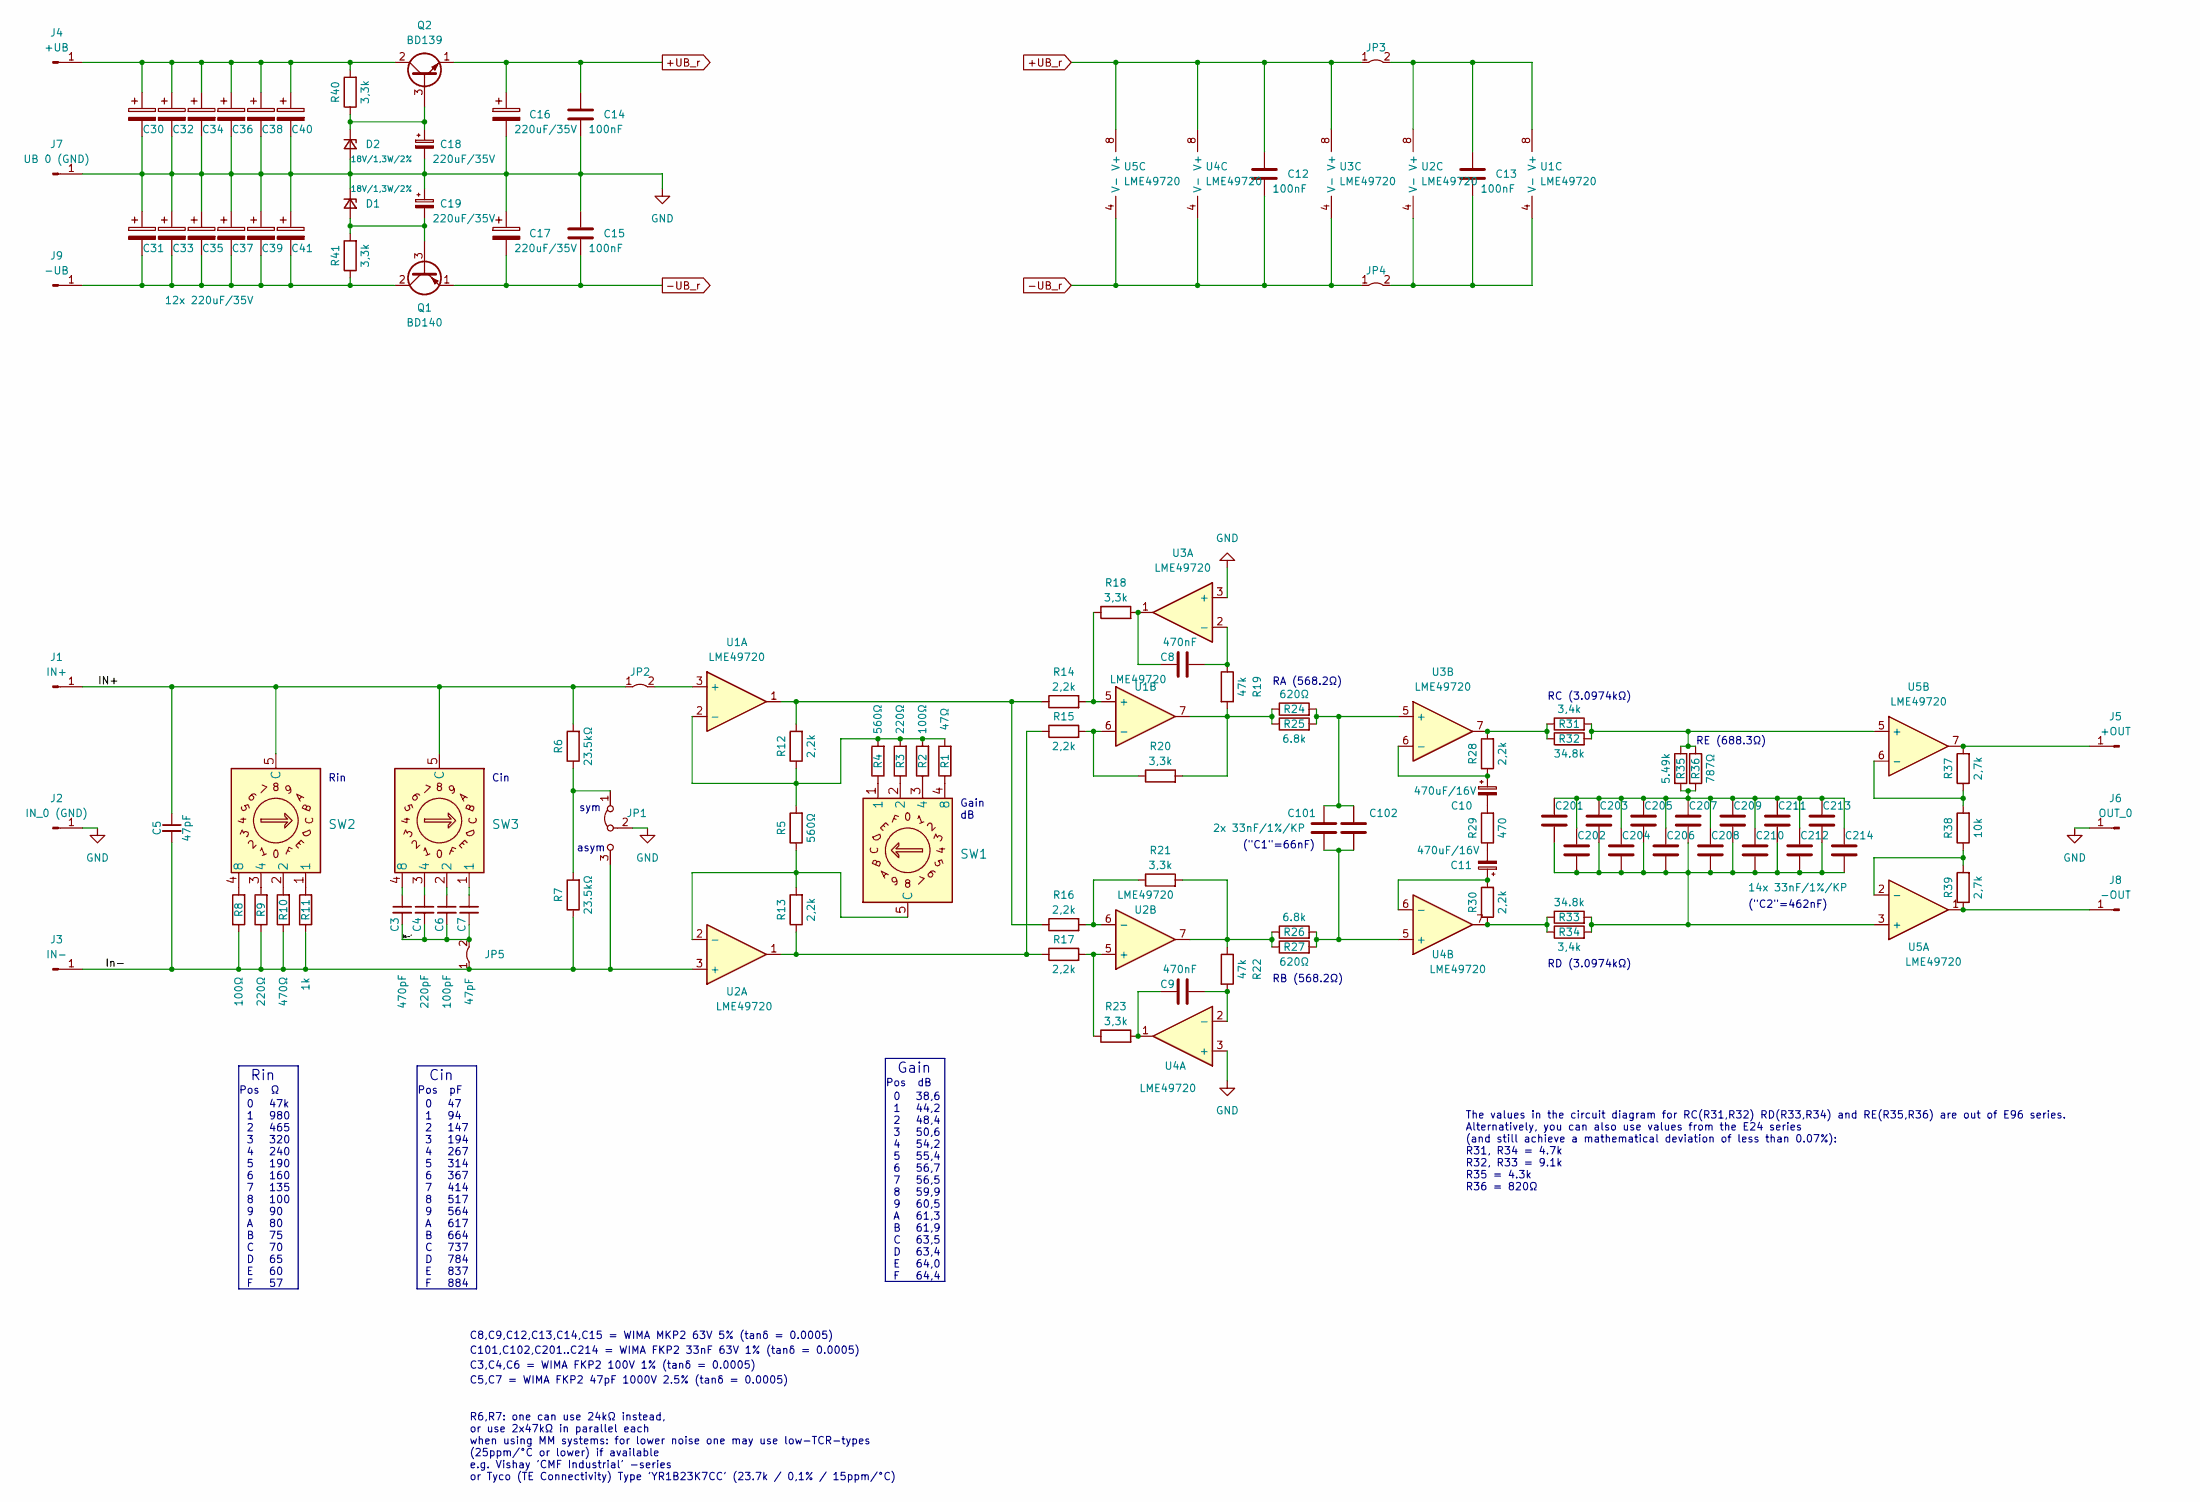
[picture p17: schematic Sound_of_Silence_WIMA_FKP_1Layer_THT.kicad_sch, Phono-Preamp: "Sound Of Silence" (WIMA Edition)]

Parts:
C3: 470pF; C_Rect_L7.2mm_W4.5mm_P5.00mm_FKS2_FKP2_MKS2_MKP2
C4: 220pF; C_Rect_L7.2mm_W4.5mm_P5.00mm_FKS2_FKP2_MKS2_MKP2
C5, C7: 47pF; C_Rect_L7.2mm_W4.5mm_P5.00mm_FKS2_FKP2_MKS2_MKP2
C6: 100pF; C_Rect_L7.2mm_W4.5mm_P5.00mm_FKS2_FKP2_MKS2_MKP2
C8, C9: 470nF; C_Rect_L7.2mm_W8.5mm_P5.00mm_FKP2_FKP2_MKS2_MKP2
C10, C11: 470uF/16V; CP_Radial_Black_D8.2mm_H12.0mm_P3.50mm_minimal_silk
C12, C13, C14, C15: 100nF; C_Rect_L7.2mm_W5.0mm_P5.00mm_FKS2_FKP2_MKS2_MKP2
C16, C17, C18, C19, C30, C32, C33, C34, C35, C36, C37, C38, C39, C40, C41: 220uF/35V; CP_Radial_Black_D8.2mm_H12.0mm_P3.50mm_minimal_silk
C31: 12x 220uF/35V; CP_Radial_Black_D8.2mm_H12.0mm_P3.50mm_minimal_silk
C101, C202, C203, C204, C205, C206, C207, C208, C209, C210, C211, C212, C213, C214: 33nF/1%/KP; C_Rect_L7.2mm_W8.5mm_P5.00mm_FKP2_FKP2_MKS2_MKP2
C102: 2x 33nF/1%/KP; C_Rect_L7.2mm_W8.5mm_P5.00mm_FKP2_FKP2_MKS2_MKP2
C201: 14x 33nF/1%/KP; C_Rect_L7.2mm_W8.5mm_P5.00mm_FKP2_FKP2_MKS2_MKP2
D1, D2: 18V/1,3W/2%; D_DO-41_SOD81_medium_P9.33mm_Horiz_minSilk
J1: IN+; Loet_Pin_D1.5mm_L14.0mm
J2: IN_0 (GND); Loet_Pin_D1.5mm_L14.0mm
J3: IN-; Loet_Pin_D1.5mm_L14.0mm
J4: +UB; Loet_Pin_D1.5mm_L14.0mm
J5: +OUT; Loet_Pin_D1.5mm_L14.0mm
J6: OUT_0; Loet_Pin_D1.5mm_L14.0mm
J7: UB 0 (GND); Loet_Pin_D1.5mm_L14.0mm
J8: -OUT; Loet_Pin_D1.5mm_L14.0mm
J9: -UB; Loet_Pin_D1.5mm_L14.0mm
JP1: Jumper_3_Bridged12; PinHeader_1x03_P2.54mm_Vertical
JP2, JP3, JP4, JP5: Jumper_2_Bridged; Drahtbruecke_10.16mm
Q1: BD140; TO-126-3_Vertical
Q2: BD139; TO-126-3_Vertical
R1: 47Ω; R_Axial_DIN0207_L6.3mm_D2.5mm_P10.16mm_Horizontal_minSilk
R2, R8: 100Ω; R_Axial_DIN0207_L6.3mm_D2.5mm_P10.16mm_Horizontal_minSilk
R3, R9: 220Ω; R_Axial_DIN0207_L6.3mm_D2.5mm_P10.16mm_Horizontal_minSilk
R4, R5: 560Ω; R_Axial_DIN0207_L6.3mm_D2.5mm_P10.16mm_Horizontal_minSilk
R6, R7: 23.5kΩ; R_Axial_DIN0207_L6.3mm_D2.5mm_P10.16mm_Horizontal_minSilk
R10: 470Ω; R_Axial_DIN0207_L6.3mm_D2.5mm_P10.16mm_Horizontal_minSilk
R11: 1k; R_Axial_DIN0207_L6.3mm_D2.5mm_P10.16mm_Horizontal_minSilk
R12, R13, R14, R15, R16, R17, R28, R30: 2,2k; R_Axial_DIN0207_L6.3mm_D2.5mm_P10.16mm_Horizontal_minSilk
R18, R20, R21, R23, R40, R41: 3,3k; R_Axial_DIN0207_L6.3mm_D2.5mm_P10.16mm_Horizontal_minSilk
R19, R22: 47k; R_Axial_DIN0207_L6.3mm_D2.5mm_P10.16mm_Horizontal_minSilk
R24, R27: 620Ω; R_Axial_DIN0207_L6.3mm_D2.5mm_P10.16mm_Horizontal_minSilk
R25, R26: 6.8k; R_Axial_DIN0207_L6.3mm_D2.5mm_P10.16mm_Horizontal_minSilk
R29: 470; R_Axial_DIN0207_L6.3mm_D2.5mm_P10.16mm_Horizontal_minSilk
R31, R34: 3,4k; R_Axial_DIN0207_L6.3mm_D2.5mm_P10.16mm_Horizontal_minSilk
R32, R33: 34.8k; R_Axial_DIN0207_L6.3mm_D2.5mm_P10.16mm_Horizontal_minSilk
R35: 5.49k; R_Axial_DIN0207_L6.3mm_D2.5mm_P10.16mm_Horizontal_minSilk
R36: 787Ω; R_Axial_DIN0207_L6.3mm_D2.5mm_P10.16mm_Horizontal_minSilk
R37, R39: 2,7k; R_Axial_DIN0207_L6.3mm_D2.5mm_P10.16mm_Horizontal_minSilk
R38: 10k; R_Axial_DIN0207_L6.3mm_D2.5mm_P10.16mm_Horizontal_minSilk
SW1, SW2, SW3: DRS4010; DRS_3016_4010_horiz_and_vert
U1, U2, U3, U4, U5: LME49720; DIP-8_W7.62mm

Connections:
+UB_r: C12.1, C14.1, C16.1, JP3.1 (A), Q2.1 (E), U3.8 (V+), U4.8 (V+), U5.8 (V+)
-UB_r: C12.2, C15.2, C17.2, JP4.1 (A), Q1.1 (E), U3.4 (V-), U4.4 (V-), U5.4 (V-)
/IN+: C5.1, J1.1, JP2.1 (A), R6.2, SW2.5 (C), SW3.5 (C)
/In-: C5.2, J3.1, JP1.3 (B), JP5.1 (A), R7.1, R8.1, R9.1, R10.1, R11.1, U2.3 (+)
/In-': C3.2, C4.2, C6.2, C7.2, JP5.2 (B)
GND: C14.2, C15.1, C16.2, C17.1, C18.2, C19.1, C30.2, C31.1, C32.2, C33.1, C34.2, C35.1, C36.2, C37.1, C38.2, C39.1, C40.2, C41.1, D1.1 (K), D2.2 (A), J2.1, J6.1, J7.1, JP1.2 (C), U3.3 (+), U4.3 (+)
unnamed: C3.1, SW3.4 (8)
unnamed: C4.1, SW3.3 (4)
unnamed: C6.1, SW3.2
unnamed: C7.1, SW3.1
unnamed: C8.1, R18.2, U3.1
unnamed: C8.2, R19.1, U3.2 (-)
unnamed: C9.1, R23.2, U4.1
unnamed: C9.2, R22.2, U4.2 (-)
unnamed: C10.1, R28.1, U3.6 (-)
unnamed: C10.2, R29.2
unnamed: C11.1, R30.2, U4.6 (-)
unnamed: C11.2, R29.1
unnamed: C13.1, JP3.2 (B), U1.8 (V+), U2.8 (V+)
unnamed: C13.2, JP4.2 (B), U1.4 (V-), U2.4 (V-)
unnamed: C18.1, D2.1 (K), Q2.3 (B), R40.1
unnamed: C19.2, D1.2 (A), Q1.3 (B), R41.2
unnamed: C30.1, C32.1, C34.1, C36.1, C38.1, C40.1, J4.1, Q2.2 (C), R40.2
unnamed: C31.2, C33.2, C35.2, C37.2, C39.2, C41.2, J9.1, Q1.2 (C), R41.1
unnamed: C101.1, C102.1, R24.2, R25.2, U3.5 (+)
unnamed: C101.2, C102.2, R26.2, R27.2, U4.5 (+)
unnamed: C201.1, C202.1, C203.1, C204.1, C205.1, C206.1, C207.1, C208.1, C209.1, C210.1, C211.1, C212.1, C213.1, C214.1, R35.2, R36.2
unnamed: C201.2, C202.2, C203.2, C204.2, C205.2, C206.2, C207.2, C208.2, C209.2, C210.2, C211.2, C212.2, C213.2, C214.2, R33.2, R34.2, U5.3 (+)
unnamed: J5.1, R37.2, U5.7
unnamed: J8.1, R39.1, U5.1
unnamed: JP1.1 (A), R6.1, R7.2
unnamed: JP2.2 (B), U1.3 (+)
unnamed: R1.1, SW1.4 (8)
unnamed: R1.2, R2.2, R3.2, R4.2, R5.2, R12.1, U1.2 (-)
unnamed: R2.1, SW1.3 (4)
unnamed: R3.1, SW1.2
unnamed: R4.1, SW1.1
unnamed: R8.2, SW2.4 (8)
unnamed: R9.2, SW2.3 (4)
unnamed: R10.2, SW2.2
unnamed: R11.2, SW2.1
unnamed: R12.2, R14.1, R16.1, U1.1
unnamed: R13.1, R15.1, R17.1, U2.1
unnamed: R5.1, R13.2, SW1.5 (C), U2.2 (-)
unnamed: R14.2, R18.1, U1.5 (+)
unnamed: R15.2, R20.1, U1.6 (-)
unnamed: R16.2, R21.1, U2.6 (-)
unnamed: R17.2, R23.1, U2.5 (+)
unnamed: R19.2, R20.2, R24.1, R25.1, U1.7
unnamed: R21.2, R22.1, R26.1, R27.1, U2.7
unnamed: R28.2, R31.1, R32.1, U3.7
unnamed: R30.1, R33.1, R34.1, U4.7
unnamed: R31.2, R32.2, R35.1, R36.1, U5.5 (+)
unnamed: R37.1, R38.2, U5.6 (-)
unnamed: R38.1, R39.2, U5.2 (-)

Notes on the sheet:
RE (688.3Ω)
Cin
RD (3.0974kΩ)
0 1 2 3 4 5 6 7 8 9 A B C D E F
asym
C3,C4,C6 = WIMA FKP2 100V 1% (tanδ = 0.0005)
("C1"=66nF)
Pos Ω
RB (568.2Ω)
Pos dB
47k 980 465 320 240 190 160 135 100 90 80 75 70 65 60 57
R6,R7: one can use 24kΩ instead, or use 2x47kΩ in parallel each when using MM systems: for lower noise one may use low-TCR-types (25ppm/°C or lower) if available e.g. Vishay 'CMF Industrial' -series or Tyco (TE Connectivity) Type 'YR1B23K7CC' (23.7k / 0,1% / 15ppm/°C)
Gain
Rin
sym
The values in the circuit diagram for RC(R31,R32) RD(R33,R34) and RE(R35,R36) are out of E96 series. Alternatively, you can also use values from the E24 series (and still achieve a mathematical deviation of less than 0.07%): R31, R34 = 4.7k R32, R33 = 9.1k R35 = 4.3k R36 = 820Ω
C8,C9,C12,C13,C14,C15 = WIMA MKP2 63V 5% (tanδ = 0.0005)
Gain dB
C5,C7 = WIMA FKP2 47pF 1000V 2.5% (tanδ = 0.0005)
47 94 147 194 267 314 367 414 517 564 617 664 737 784 837 884
C101,C102,C201..C214 = WIMA FKP2 33nF 63V 1% (tanδ = 0.0005)
38,6 44,2 48,4 50,6 54,2 55,4 56,7 56,5 59,9 60,5 61,3 61,9 63,5 63,4 64,0 64,4
RA (568.2Ω)
RC (3.0974kΩ)
Pos pF
("C2"=462nF)

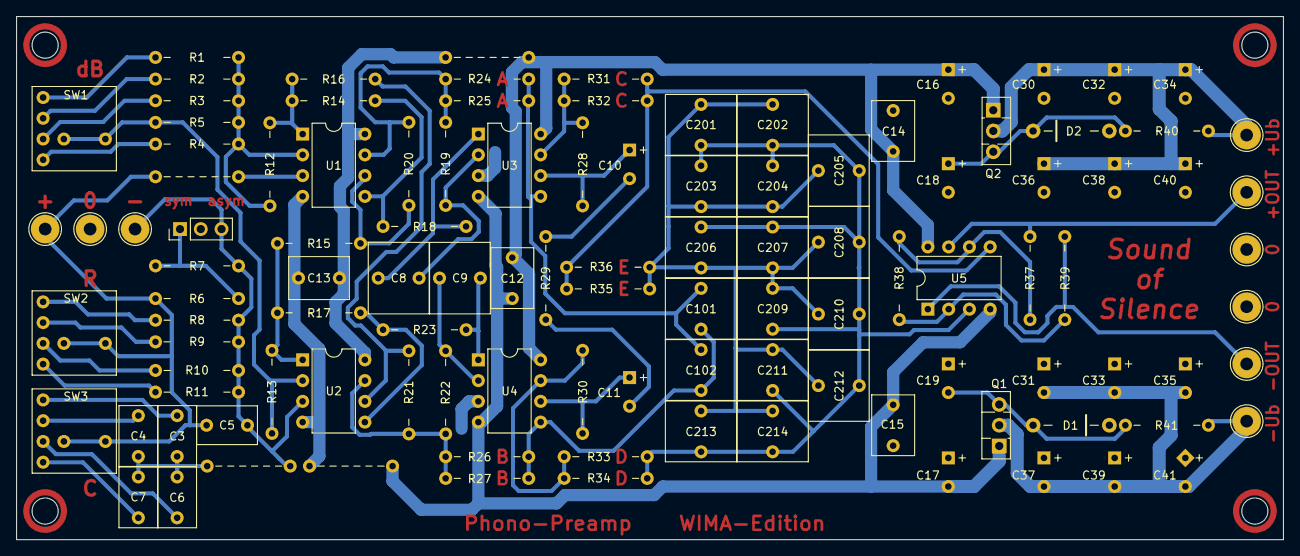
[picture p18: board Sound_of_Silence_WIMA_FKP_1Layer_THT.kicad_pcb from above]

Board: 2 copper layers, 155.0 x 64.0 mm, 112 parts (0 on the bottom side), 55 nets.
